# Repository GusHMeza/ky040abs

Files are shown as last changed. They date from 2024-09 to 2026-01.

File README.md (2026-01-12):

# ky040abs
Turn a KY040 incremental encoder to an absolute encoder with a 1 wire interface.
The KiCAD project is provided for the adapter board. 

IMPORTANT: Use avrboy by kimio-kosaka to program the ATTINY10 chip before soldering it to this adapter module. The PCB does not have a TPI interface connector.

# HOW TO USE
1. Flash an ATTINY10 chip with the provided script.
2. Use the suggested connector in the BOM or solder wires to the power inputs and the signal wire.
3. Power the module.
4. The SIG wire works as an active HIGH input, when it receives a HIGH pulse, it switches to an active HIGH output. I.e. use an I/O pin from a MCU to pulse the SIG wire, then read how many pulses the ky040abs answers with.
5. To adjust the resolution (given you have a gear ratio between the encoder and and a spinning shaft), modify the *angulo_en_pulsos* variable.
6. The provided code shows a bidirectional rotation reading, where the ATTINY10 starts at 15 counts that either increment up to 30 or decrement down to 0 depending on the direction of rotation. 





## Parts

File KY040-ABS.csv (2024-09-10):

Reference | Value | Datasheet | Footprint | Qty
C1 | .1uF | ~ | Capacitor_SMD:C_0603_1608Metric | 1
D1 | LED | ~ | LED_SMD:LED_0603_1608Metric | 1
J1 | Conn_01x03_Pin | ~ | Connector_JST:JST_PH_S3B-PH-K_1x03_P2.00mm_Horizontal | 1
R1,R2 | 2kR | ~ | Resistor_SMD:R_0603_1608Metric | 2
R7 | 1k | ~ | Resistor_SMD:R_0603_1608Metric | 1
SW1 | RotaryEncoder_Switch | ~ | Rotary_Encoder:RotaryEncoder_Alps_EC11E-Switch_Vertical_H20mm_CircularMountingHoles | 1
U1 | ATtiny10-TS | http://ww1.microchip.com/downloads/en/DeviceDoc/Atmel-8127-AVR-8-bit-Microcontroller-ATtiny4-ATtiny5-ATtiny9-ATtiny10_Datasheet.pdf | Package_TO_SOT_SMD:SOT-23-6 | 1

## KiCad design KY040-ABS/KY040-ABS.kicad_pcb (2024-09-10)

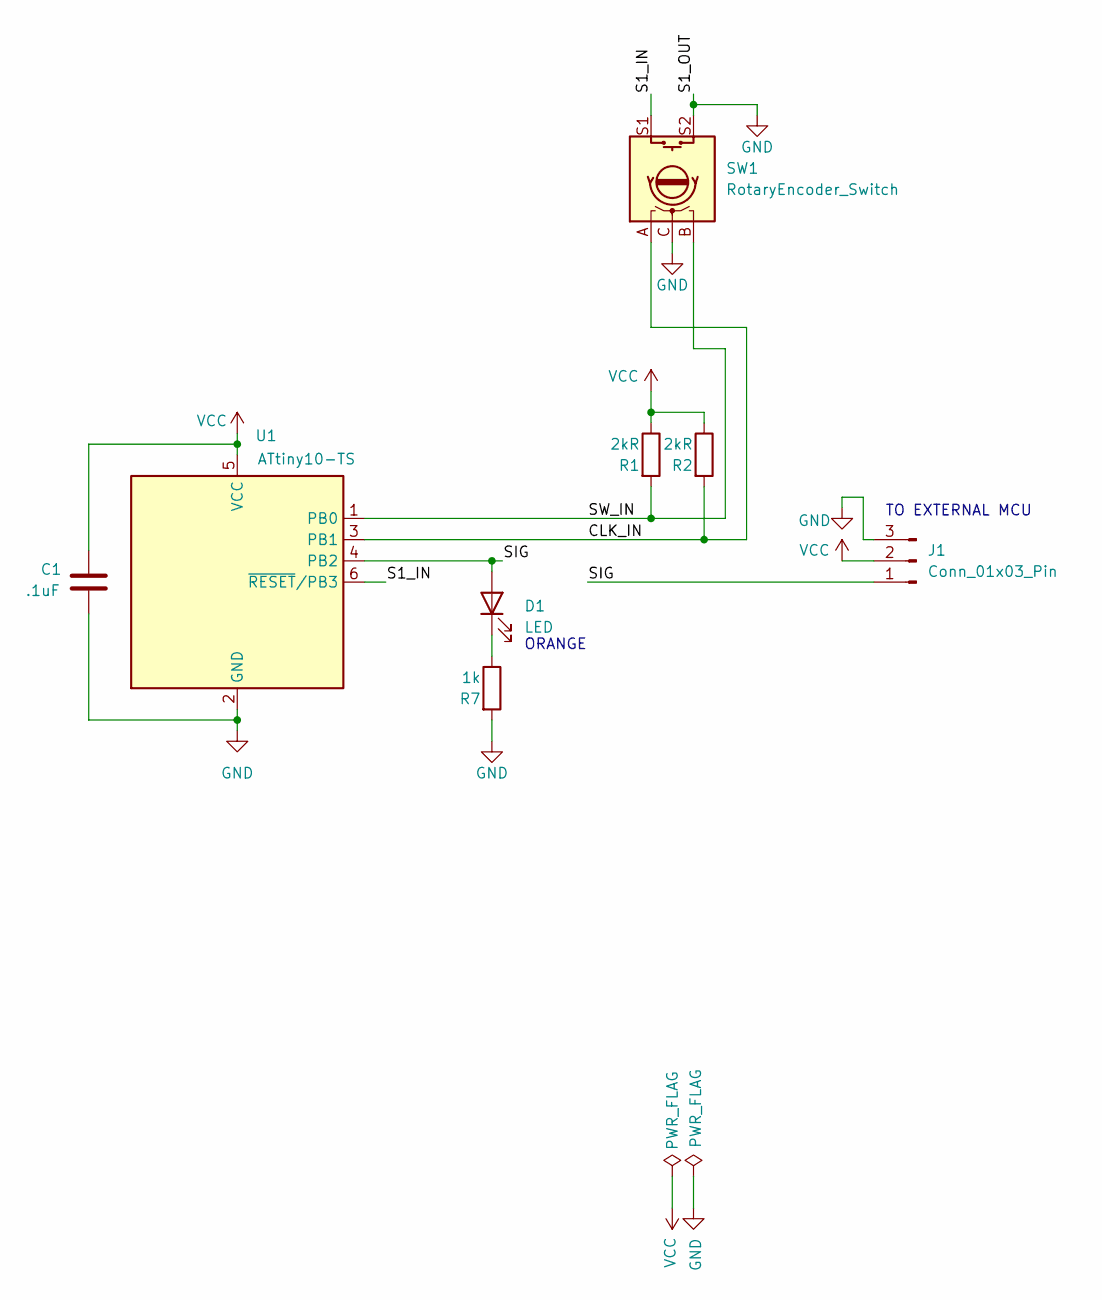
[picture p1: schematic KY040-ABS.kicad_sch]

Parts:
C1: .1uF; C_0603_1608Metric
D1: LED; LED_0603_1608Metric
J1: Conn_01x03_Pin; JST_PH_S3B-PH-K_1x03_P2.00mm_Horizontal
R1, R2: 2kR; R_0603_1608Metric
R7: 1k; R_0603_1608Metric
SW1: RotaryEncoder_Switch; RotaryEncoder_Alps_EC11E-Switch_Vertical_H20mm_CircularMoun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
U1: ATtiny10-TS; SOT-23-6

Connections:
/CLK_IN: R2.2, SW1.A, U1.3 (PB1)
/S1_IN: SW1.S1, U1.6 (~RESET/PB3)
/SIG: D1.2 (A), J1.1, U1.4 (PB2)
/SW_IN: R1.2, SW1.B, U1.1 (PB0)
GND: C1.2, J1.3, R7.2, SW1.C, SW1.S2, U1.2 (GND)
unnamed: D1.1 (K), R7.1
VCC: C1.1, J1.2, R1.1, R2.1, U1.5 (VCC)

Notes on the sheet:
ORANGE
TO EXTERNAL MCU

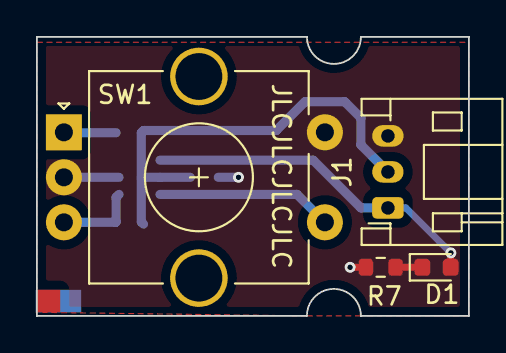
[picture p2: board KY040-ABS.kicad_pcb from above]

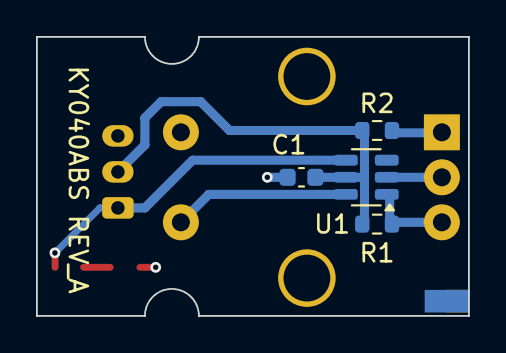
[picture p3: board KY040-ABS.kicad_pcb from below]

Board: 2 copper layers, 24.0 x 15.5 mm, 8 parts (4 on the bottom side), 7 nets.
